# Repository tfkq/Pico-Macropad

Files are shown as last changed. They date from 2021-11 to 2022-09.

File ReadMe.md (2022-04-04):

# Pico-Macropad

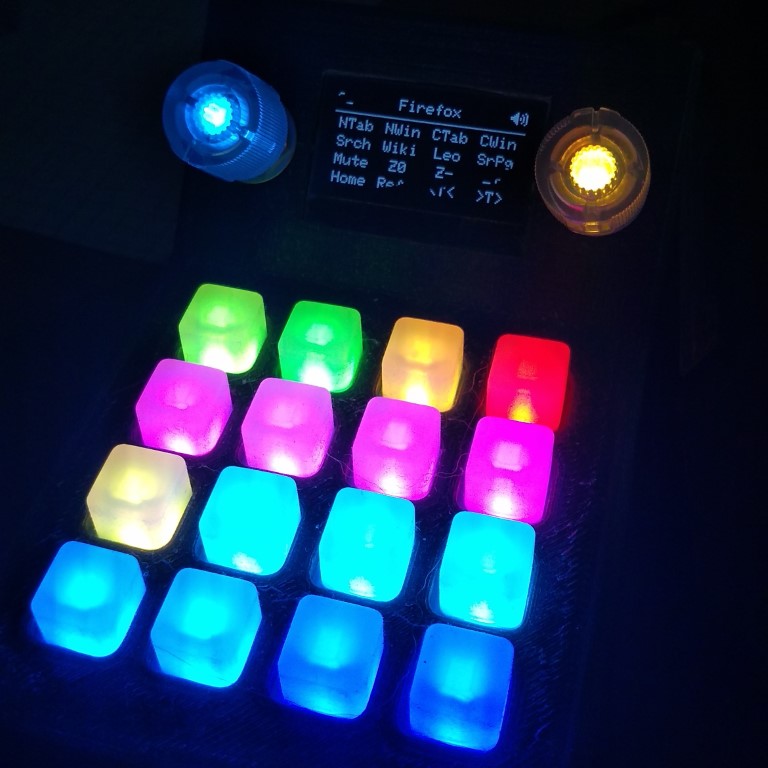
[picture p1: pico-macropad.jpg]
pico-macropad


A custom macropad built out of a Trellis Keypad, a display, rotary encoders and an Raspberry Pi Pico

## Function

This macropad features 16 RGB-lit keys to program to your own pleasure! The display shows the name of each key, so you'll remember what each of these does. Also, thanks to the rotary encoders you are not limited to 16 keys, you can create your own menu for every app you like. To switch between these menus, simply rotate the left encoder. The one on the right is used for media control, so you can adjust the volume and Play/Pause your music.

How to create a configuration: [Config-Creation](#Config-Creation)

## Construction

### Materials and parts

| Part | Cost | Links |
| --- | --- | --- |
| Raspberry Pi Pico | 4.10 €  | [Berrybase](https://www.berrybase.de/neu/raspberry-pi-pico-rp2040-mikrocontroller-board?c=2461) |
| Sparkfun RGB Rotary Encoder (2x) | 9.30 €  | [Berrybase](https://www.berrybase.de/bauelemente/passive-bauelemente/potentiometer/drehimpulsgeber/rotary-encoder/inkrementalgeber-rgb-beleuchtet) |
| Rotary knob, transparent (2x) | 1.80 €  | [Berrybase](https://www.berrybase.de/bauelemente/passive-bauelemente/potentiometer/drehpotis/drehknopf-f-252-r-ger-228-ndelte-6-0mm-achse-transparent) |
| Adafruit NeoTrellis Driver PCB | 12.90 € | [Berrybase](https://www.berrybase.de/neu/adafruit-neotrellis-rgb-treiber-pcb-f-252-r-4x4-keypad?c=2434) |
| Adafruit Silikon Elastomer 4x4 Button Keypad | 5.10 €  | [Berrybase](https://www.berrybase.de/sensoren-module/eingabe/adafruit-silikon-elastomer-4x4-button-keypad-f-252-r-3mm-leds) |
| Monochromes 1.3" 128x64 OLED Display - STEMMA QT / Qwiic | 20.55 € | [Berrybase](https://www.berrybase.de/sensoren-module/displays/oled-displays/monochromes-1.3-128x64-oled-display-stemma-qt/qwiic) |
| Screws, 3mm in diameter, 16mm in length (4x) | ? | had them laying around |

### 3D-prints

I designed my own case and printed it with PLA ([Blue Pearl](https://www.dasfilament.de/filament-spulen/pla-1-75-mm/405/pla-filament-1-75-mm-blue-pearl?c=11)). I've put the Skynet logo on the front, because I felt the need to put something there and I have just watched Terminator 2. You can find the CAD and STL files in `doc/cad-files/`.

### Assembly

1. Wiring:
	There are some images of the wiring in the `doc` folder. However, there are some errors in the schematics that I haven't fixed yet.
2. Putting the parts together:
	I used four screws with a diameter of 3mm and a length of 16mm
	I taped some foam on top of the legs for the trellis board, so it can't wiggle too much

## Programming

### Platform
I chose the Raspberry Pi Pico because of its speed and ability to emulate a keyboard. But for the programming part I sticked with the Arduino platform, because I already know how it works and is compatible with all devices. This was a problem with micropython, as it doesn't have widespread support for every module imaginable. I also decided myself against Cuircuit-Python, once because using a display with it is kinda a struggle, second because I programmed enough Python in the past, and I wanted to practice a little bit of C++.

Secondly, as I had some trouble sending special keycodes (Volume UP and DOWN, Play/Pause, etc) with the Keyboard-library, I decided to send a special shortcut instead, wich would be caught by an AutoHotKey script (It's Windows only, sadly, other platforms would need to search for an alternative).

### Source-Code for RPi Pico

The source-code is divided into different files, here is a short summary of them:

| file | description |
| --- | --- |
| **Pico-Macropad.ino** | main file, brings everything together by telling the other modules what to do |
| config.h | saves the configuration of shrotcuts |
| display.h | controls the OLED-display |
| display_animation.h | saves data for the startup-animation on the display |
| led_controller.h | responsible for setting the brightness of all the leds |
| neotrellis.h | controls and reads the Adafruit Neotrellis board |
| rotary_encoder.h | controls and reads the two rotary encoders |
| shortcut.h | uses the the `Keyboard.h`-library to send the sortcuts to your PC |
| *macropad.ahk* | the AHK-script. Not necessarily the one I'm using, but it is A script |

### AutoHotKey-Script

At first I wanted to create every shortcut inside the C++-program. However, I wanted to build a [Config-Creator](https://github.com/zauberwild/Pico-Macropad-Config-Creator) to create the shortcuts with a GUI. This means, that the Pico will send a generic shortcut (`F24` + something), which will be catched by an AHK-script. Finally, the script will perform all the tasks.

### Config Creation

To create a Configuration, you need to head over to my [Config-Creator](https://github.com/zauberwild/Pico-Macropad-Config-Creator).

## Credits and License

This project is under the MIT license. If you reuse any parts of this and publish it, please be so kind to mention me / this repo.

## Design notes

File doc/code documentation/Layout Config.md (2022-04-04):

# Layout Config

This file describes the format of the config files found in `/data`.

> Example of config file:
> ````
> MAIN	255	0	0
> Micro	$F240#0.	255	255	0
> Prev	$F240#1.	255	191	0
> Next	$F240#2.	255	191	0
> Lock	$F240#3.	255	127	0
> StandBy	$F240#4.	255	64	0
> ShutDn	$F240#5.	255	0	0
> -
> -
> -
> ~PROGRA
> -
> -
> ````

**Layout Name and Color**

The first line contains the Layout name (max. 6 chars.) and color as RGB (0-255)

**Buttons**

The Buttons are given in the following lines, each line for one button.'
These lines also contain the name for the button (max. 6 chars.), then the macros (max. 63 chars.), then the color as RGB (0-255)

**Formatting**

The different fields are always seperated by `TABs`, so that Spaces can still be used if wanted to.

**Special Signs**

| Sign | |
| --- | --- |
| **`-`** | empty field. this button will not perform any action and will be turned off |
| **`~`** | special functions. there will no macros performed on these buttons. Instead a function will be called.<br />Names for these fields can be given after the `~` (max. 6 char.; without  `~`) |

*Sign `~`:*

- `~PROG`: change the selected layout

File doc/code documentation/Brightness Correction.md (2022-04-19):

# Brightness Correction

When turning the rotary encoder for brightness, the scale, and thus the brightness, would be changed linearly. However, the resulting change of brightness doesn't seem linear to the human eye, and in order to fix that, I used a ~~logistic~~ *apparently exponential* function, that would convert the mathematically linear scale to perceptually linear scale.

> inspired from this answer on stack-exchange: https://electronics.stackexchange.com/a/11100

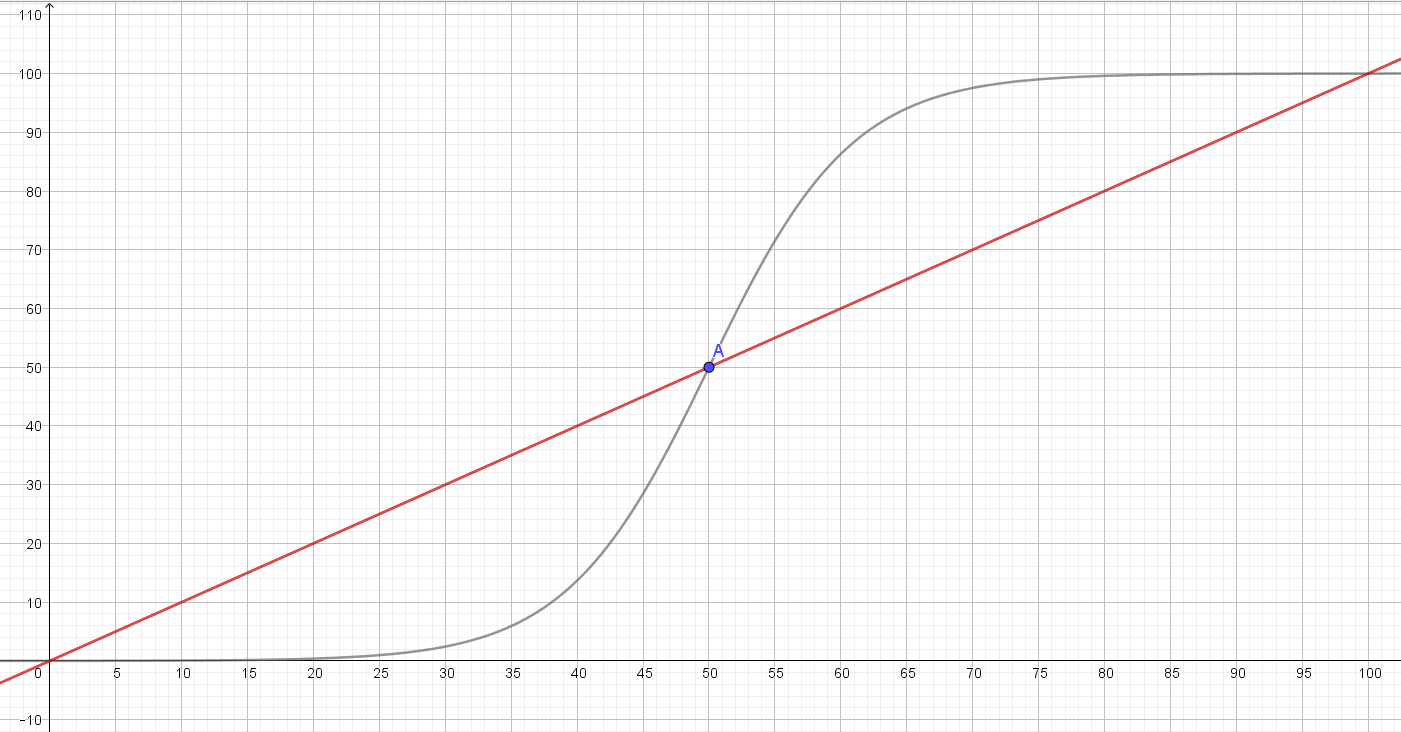
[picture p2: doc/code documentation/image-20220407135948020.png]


In the above image, the red line shows the linear scale of the direct input. The dark line is the logistic scale which should be applied to the LED's.

The function for logistic growth looks like this:
$$
f(x) = \frac{
	G \cdot f_0
}{
	f_0 + (G-f_0) \cdot e^{
		-k\cdot G \cdot x
	}
}
$$
Where $G$ is the upper boundary, $f_0$ the value of $f(0)$ and $k$ a factor (as it seems in $]0,1[$ ).

We know that $G=100$ and $f_0 = 0.01 \approx 0$ (the lowest value would be zero, but the function doesn't allow a start at zero, so we approximate it with 0.001). Also we know  that $f(x)$ includes $P(50|50)$. This way we can calculate $k$:
$$
\begin{align}
50 &= \frac{
	100 \cdot 0.01
}{
	0.01 + (100 - 0.01) \cdot e^{
		-k \cdot 100 \cdot 50
	}
}
\\
k &= 0.00184
\end{align}
$$

This gives us the equation for a corrected brightness:
$$
\begin{align}
\text{brightness} &= \frac{
	100 \cdot 0.01
}{
	0.01 + (100-0.01) \cdot
	e^{
		-0.00184 \cdot 100 \cdot \text{raw\_brightness}
	}
}
\\
\text{brightness} &= \frac{
	1
}{
	0.01 + (99.99) \cdot 
	e^{
		-0.184 \cdot \text{raw\_brightness}
	}
}
\\
\\
\text{brightness} &\approx \frac{
	1
}{
	100 \cdot 
	e^{
		-0.184 \cdot \text{raw\_brightness}
	}
}
\end{align}
$$
Which leads to the final code:

````c++
brightness = 1 / (100 * pow(2.718, -0.184 * raw_brightness));
if(brightness < 0 )
    brightness = 0;
else if(brightness > 100)
    brightness = 100;
````

---

EDIT:

the optimised function (in green) isn't logistic at all and doesn't strictly meet my requirements:

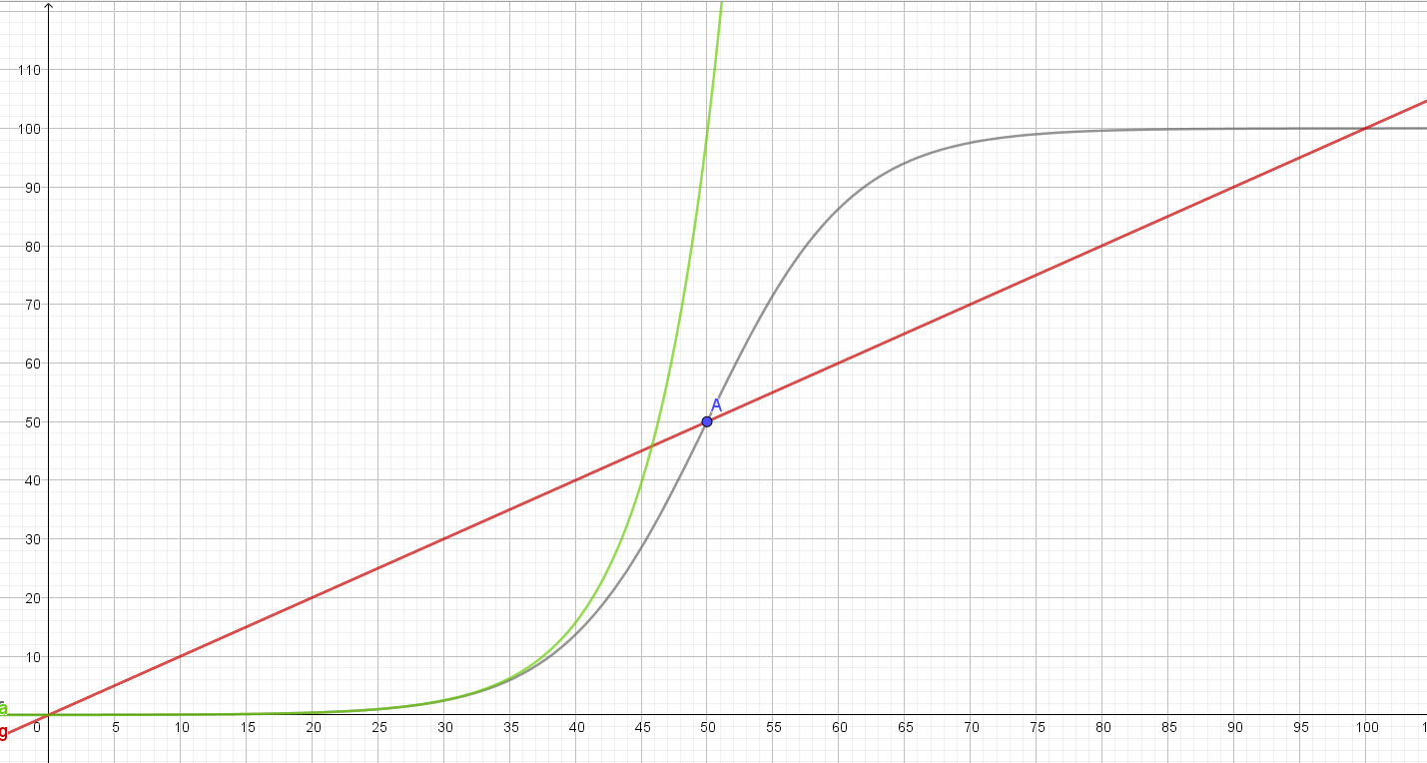
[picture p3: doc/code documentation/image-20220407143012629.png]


However, it still works well enough, except that i need to cap `raw_brightness` a little bit earlier than 100, but at 50. *it even feels somewhat better than not optimised logistic.*

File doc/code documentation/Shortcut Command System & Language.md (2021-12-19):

# Shortcut Command System & Language

I created my own Command Language which would be easy to parse and doesn't require line breaks. This system supports all modifier on Windows (and maybe UNIX, but I haven't tested) and special keys to be pressed and released in whatever order.

## Sending letters / text

To send plain text you just use ... plain text! For example if you want a macro typing "Hello World!" for you, you would just type it like that.

However, there are some problems when your computer is set to a keyboard-layout other than the standard English (QWERTY) one. Especially special letters (@,#,+,*,...) are problematic, and I couldn't find a way to fix this yet. 

## Commands

Generally speaking, all commands start with `$` and only contain two letters, with some exceptions. There are also two type of commands: First the modifier keys, which are toggled when using its command. The first use presses the key down, the second one releases its, and so on. Second, other special keys, like Enter/Return, Insert, Delete, etc. These are just pressed once and than you're done. Following is a list with all commands.

**One important thing: the command system is Case-Sensitive.**

### Toggled commands

1. *these are always the one on the left side of the keyboard*
2. *the keyword in the bracket is the input to the [Keyboard library](https://www.arduino.cc/reference/en/language/functions/usb/keyboard/) (`Keyboard.print(<Keyword>);`)*
3. *as mentioned, these keys are toggled on and off, so don't forget to toggle them off at the end*

| Command | Explanation |
| --- | --- |
| $W | Windows / Meta key (`KEY_LEFT_GUI`) |
| $C | Control Key (`KEY_LEFT_CTRL`) |
| $S | Shift Key (`KEY_LEFT_SHIFT`) |
| $A | Alt Key (`KEY_LEFT_ALT`) |

### Special keys

- *these are just pressed once and will be quickly released*

| Command | Explanation |
| --- | --- |
| $E | Enter / Return |
| $T | Tab |
| $* | Escape |
| $1 | Home / Pos1 |
| $0 | End |
| $I | Insert |
| $D | Delete |
| $$ | $ (in case you need a dollar sign) | |
| $Fxx | All the F-keys your computer supports. "xx" can be replaced with a number from 1 to 24 |
| $dxxxx$ | This one starts a delay. The time is given in milliseconds and is limited to four digits. Please note that this stops the whole program and it waits until the time is past. You won't be able to do other things with it in the meantime. |

### Examples

- `$We$W` opens the explorer on Windows
- `$Cko$C` opens a folder in VS Code
- `$Wr$W$d250$cmd$E` starts the command palette (the delay gives Windows enough time to start Run)
- `$We$W$d500$vv$E$d250$g$E$d250$a$E$d259$r$E`: This beast starts the explorer, navigates to my folder of this project and opens the ReadMe

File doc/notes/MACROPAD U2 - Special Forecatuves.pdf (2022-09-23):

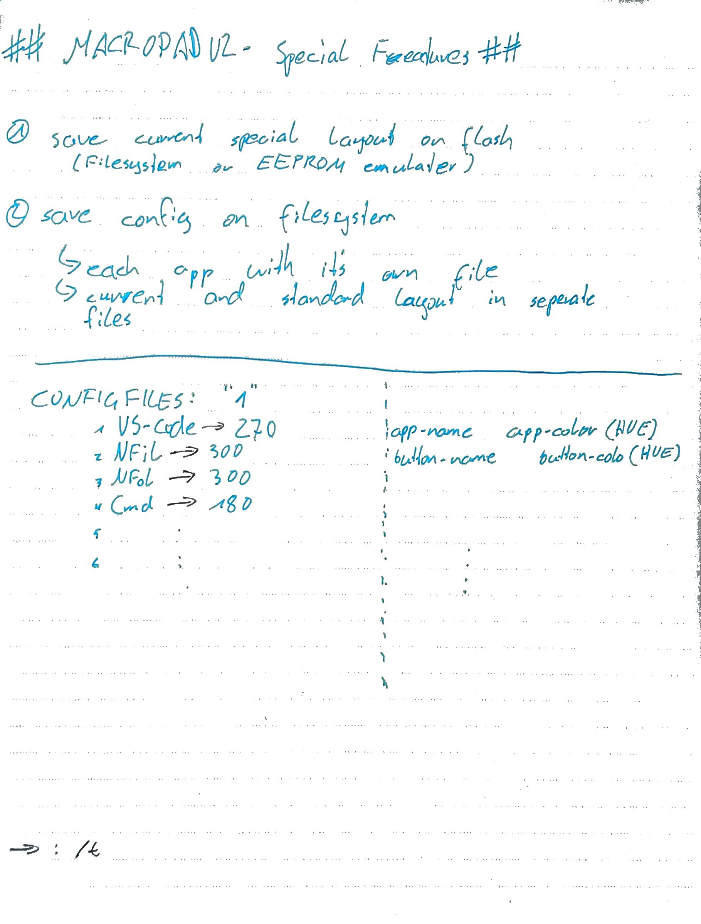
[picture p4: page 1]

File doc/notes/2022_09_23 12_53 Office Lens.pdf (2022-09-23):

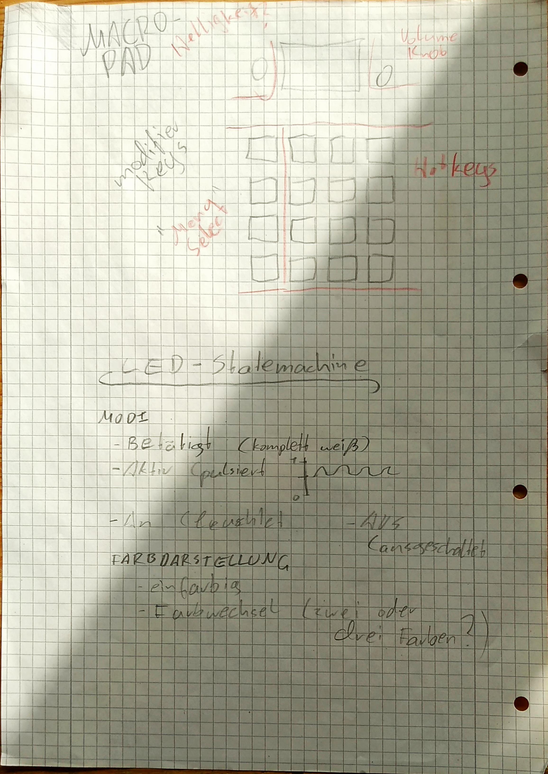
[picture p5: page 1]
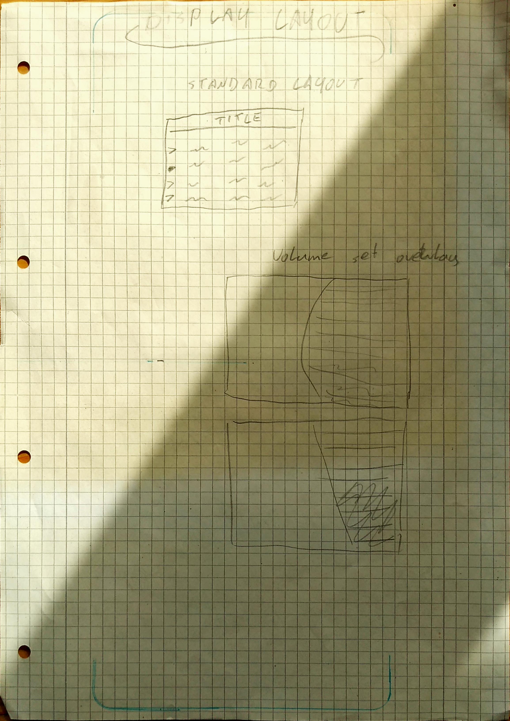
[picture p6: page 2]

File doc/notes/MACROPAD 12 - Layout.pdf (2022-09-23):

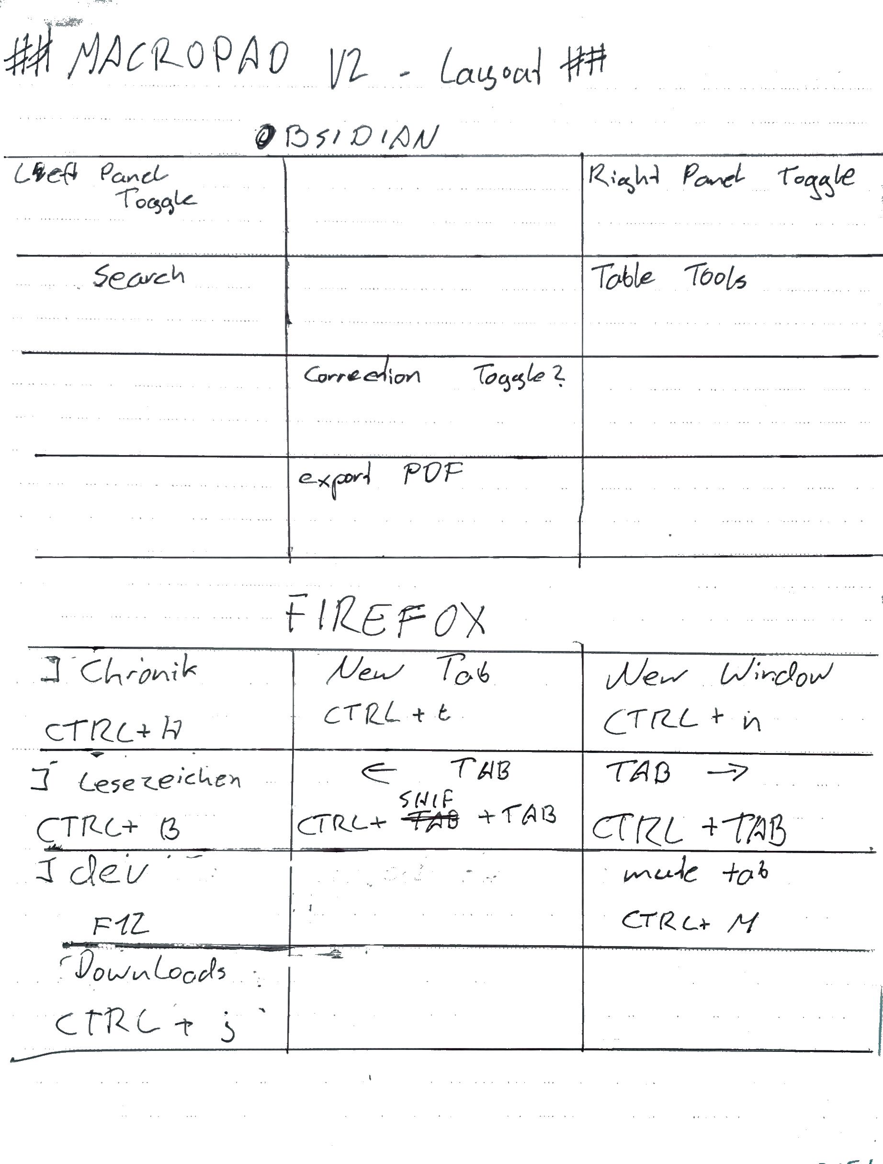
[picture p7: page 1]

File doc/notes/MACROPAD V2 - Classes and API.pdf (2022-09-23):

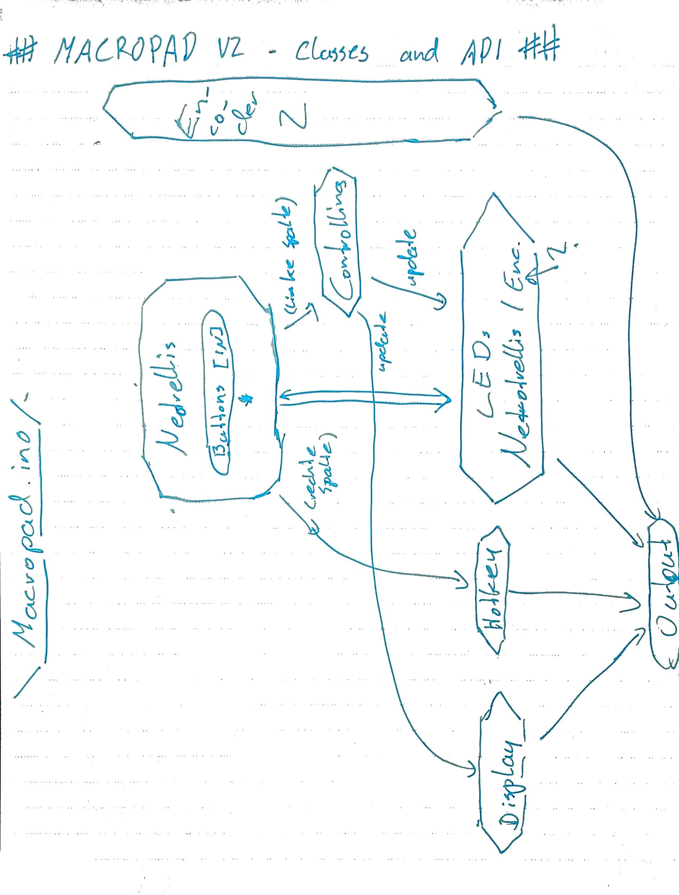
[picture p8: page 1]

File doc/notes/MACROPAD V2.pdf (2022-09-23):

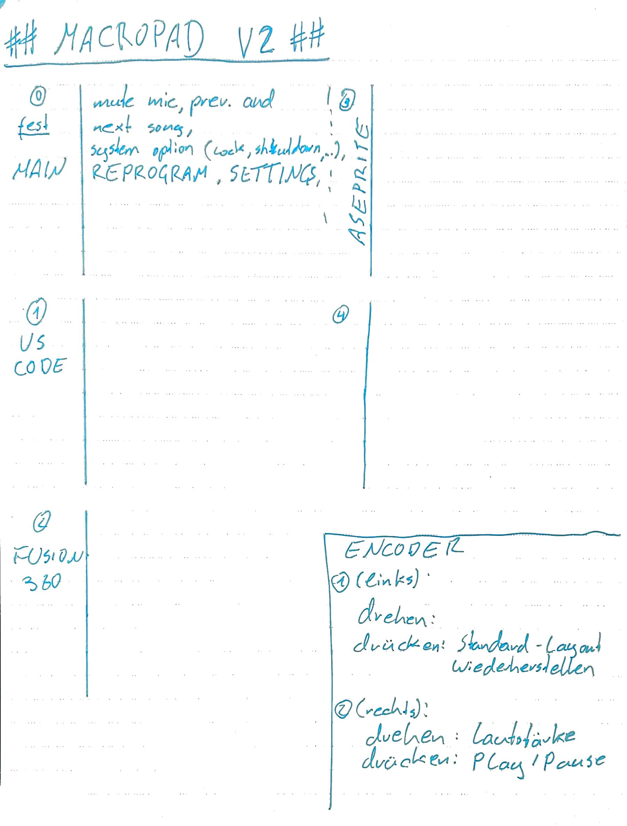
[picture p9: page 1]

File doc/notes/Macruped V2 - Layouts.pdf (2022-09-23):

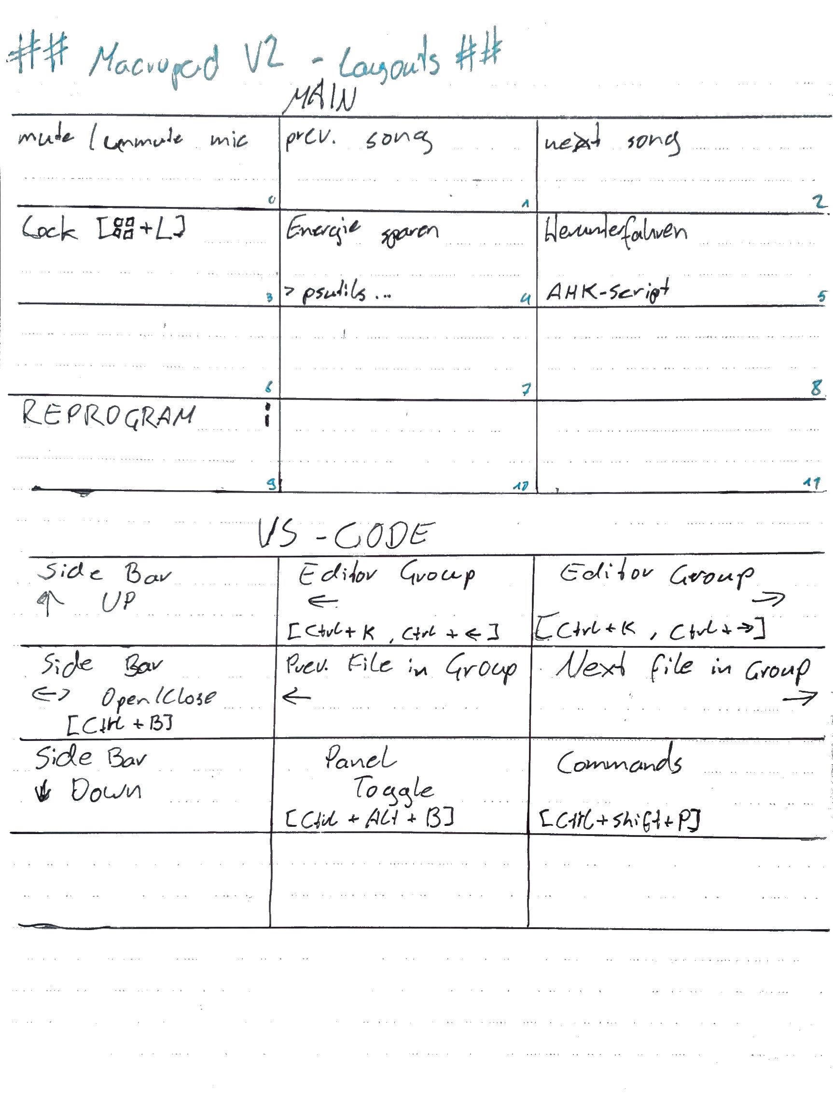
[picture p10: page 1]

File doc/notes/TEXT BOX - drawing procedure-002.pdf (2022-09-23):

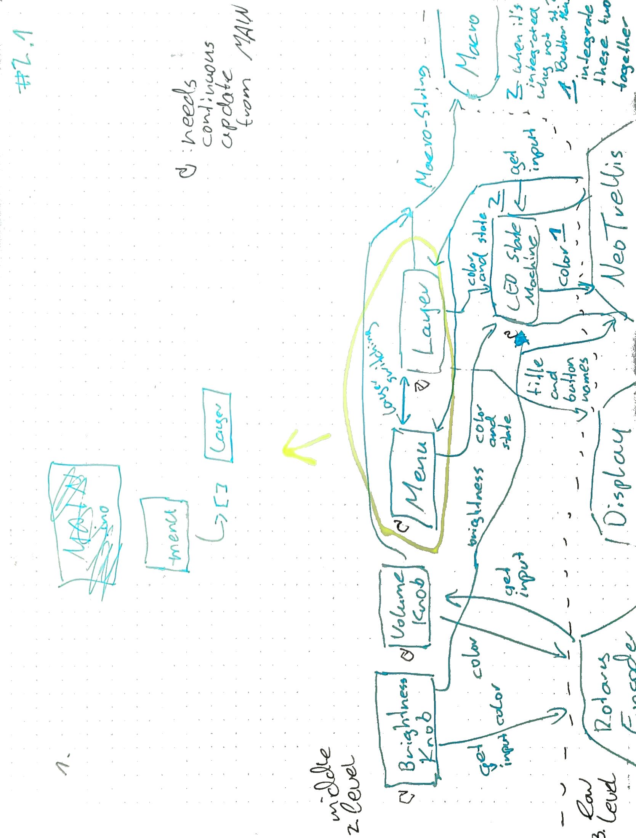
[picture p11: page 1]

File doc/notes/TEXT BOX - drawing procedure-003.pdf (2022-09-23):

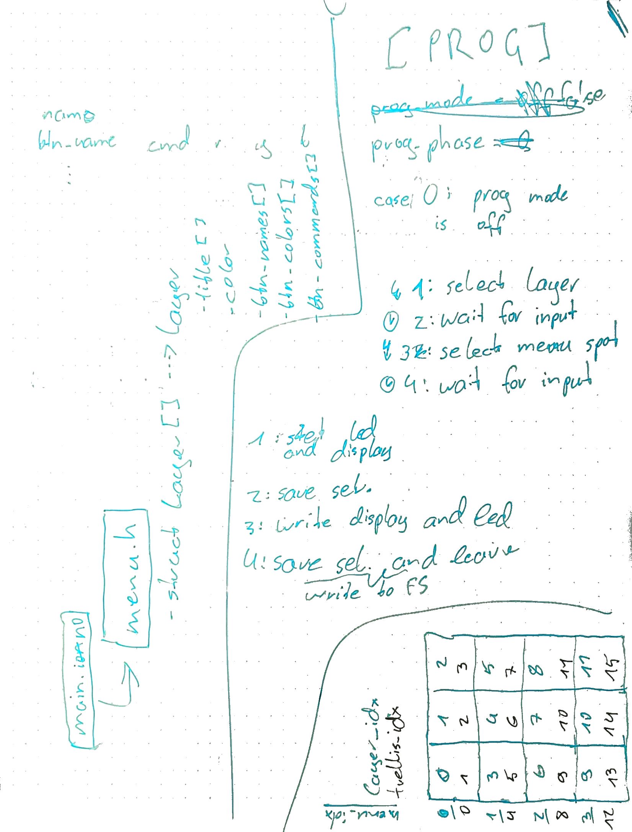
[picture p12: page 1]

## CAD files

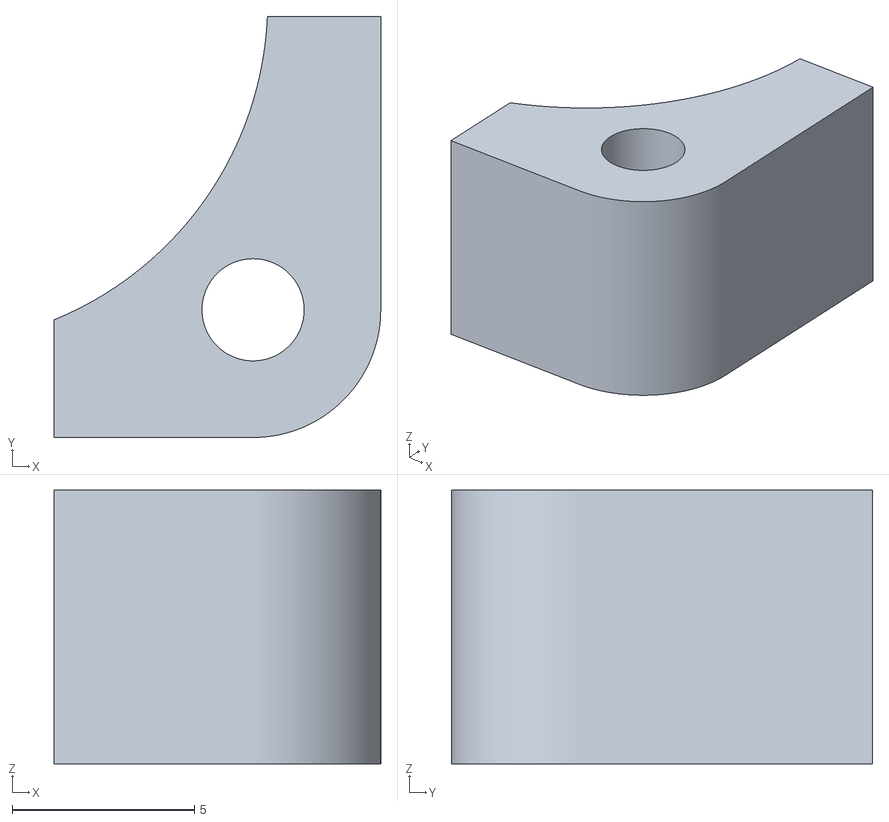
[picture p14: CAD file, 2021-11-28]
doc/cad-files/Halterung vorne 1.stl
8.95 x 11.5 x 7.50

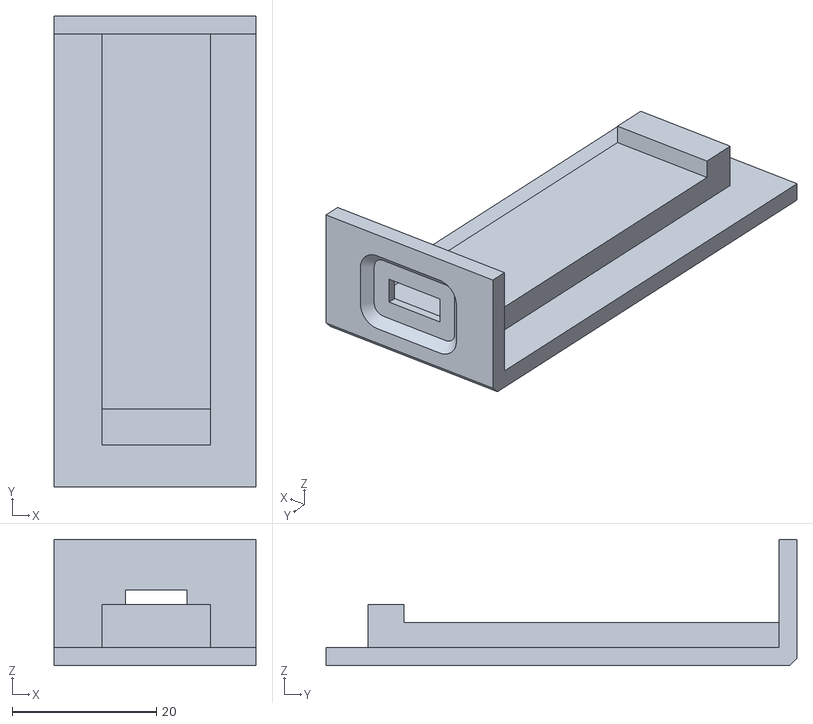
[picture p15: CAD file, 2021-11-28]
doc/cad-files/test files/Pico.stl
28.0 x 65.3 x 17.5

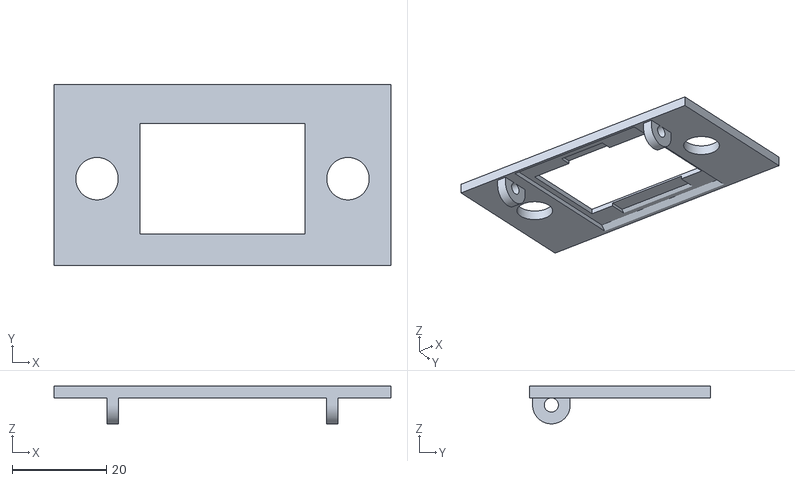
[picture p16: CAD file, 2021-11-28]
doc/cad-files/test files/DisplayUndRot.stl
71.5 x 38.4 x 8.00

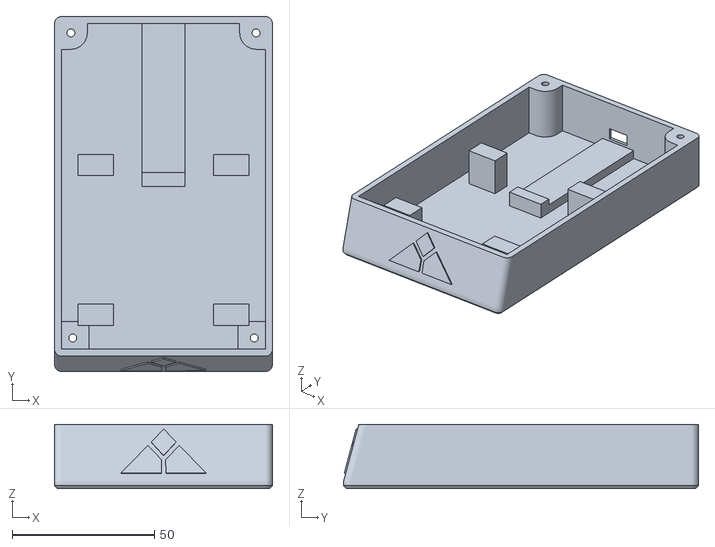
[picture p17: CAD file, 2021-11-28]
doc/cad-files/Unterseite_25mm_Skynet.stl
76.5 x 124.6 x 22.5

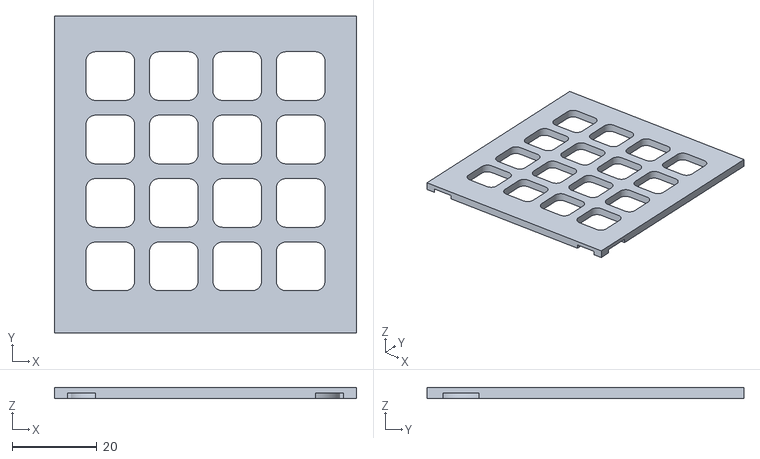
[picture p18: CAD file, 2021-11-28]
doc/cad-files/test files/TrellisKeypad.stl
71.5 x 74.9 x 2.50

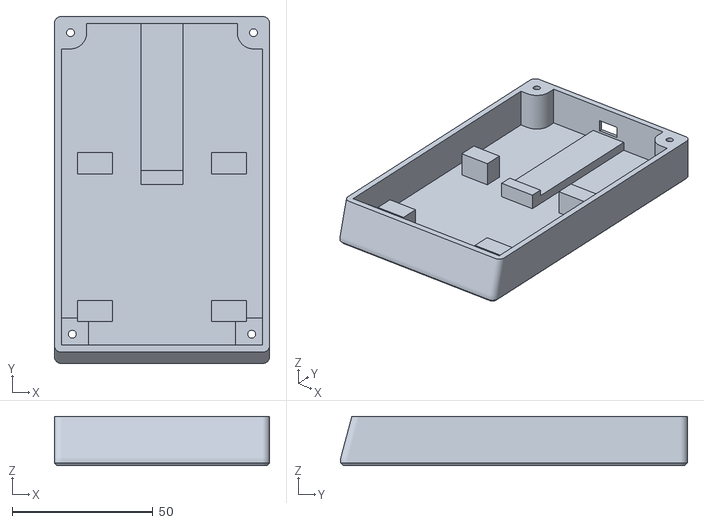
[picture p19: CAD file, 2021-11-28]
doc/cad-files/Unterseite_20mm.stl
76.5 x 123.2 x 17.5

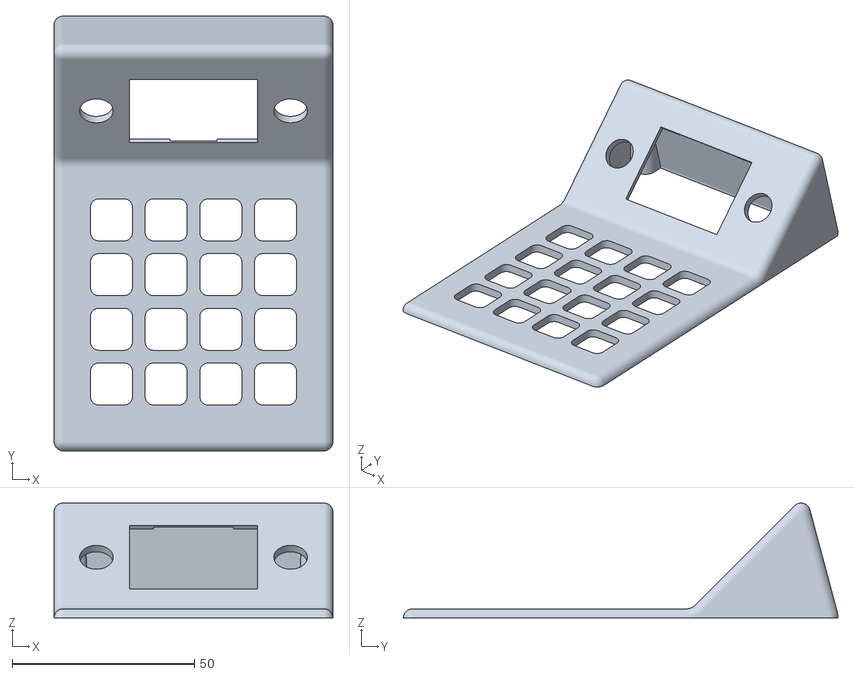
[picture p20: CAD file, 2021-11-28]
doc/cad-files/Oberseite.stl
76.5 x 119.2 x 31.5

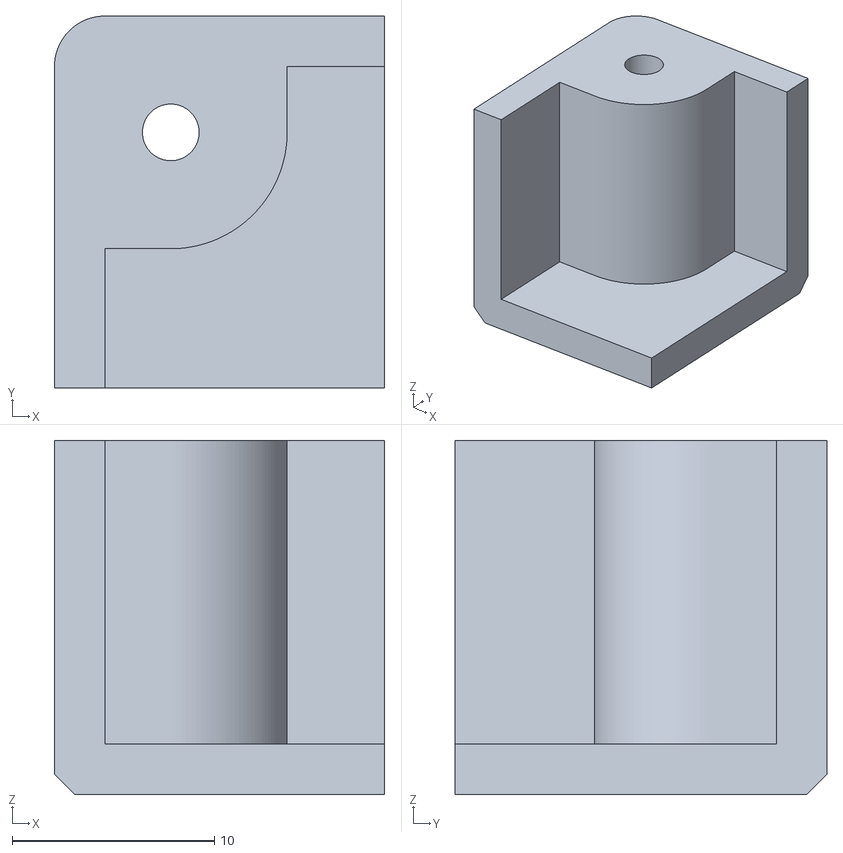
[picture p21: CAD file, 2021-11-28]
doc/cad-files/test files/Screws.stl
16.3 x 18.4 x 17.5

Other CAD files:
doc/cad-files/Halterung vorne 2.stl

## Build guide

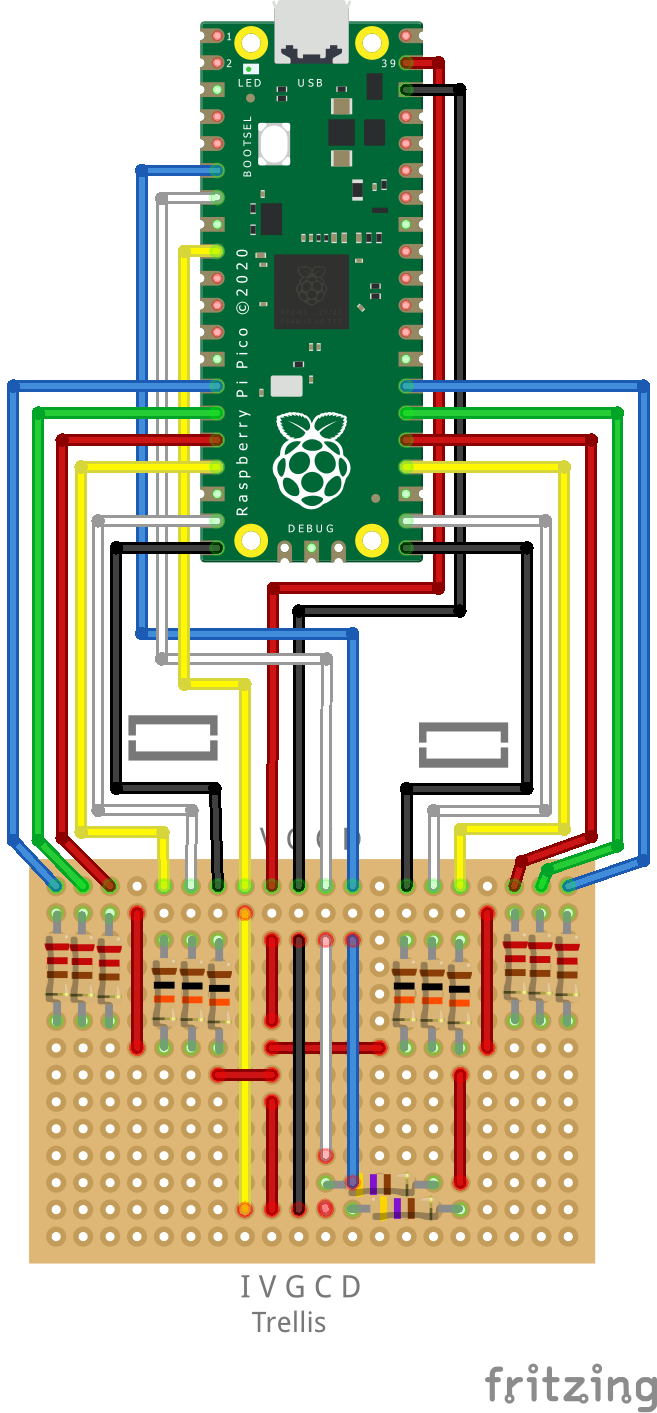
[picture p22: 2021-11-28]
doc/wiring-schematics/wiring pcb_Steckplatine.png

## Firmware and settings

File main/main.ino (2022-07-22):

//* SETTINGS
#define MAX_NAME_LENGTH 6
#define MAX_MACRO_LENGTH 63
#define MAX_NUMBER_LAYOUTS 12
#define DISPLAY_TIMEOUT 5000		 // time it takes for the display to turn off [ms]
#define DISPLAY_UPDATE_TIME 500		 // time between the display updates [ms]
#define TRELLIS_LED_UPDATE_TIME 50	 // time between the led updates [ms]
#define DEBOUNCE_TIME 5				 // debounce time for the rotary encoder [ms]
#define STEPS_PER_VOLUME 1			 // steps the volume knob needs to be turned to send a volume command
#define BRIGHTNESS_STEPS_PER_STEPS 2 // how much does the brightness change per encoder step
double raw_brightness = 40;			 // brightness percentage (0%-100%); used to calculate a corrected version
double brightness;					 // brightness percentage (0%-100%); use this one, because it is corrected

unsigned long last_input = 0; // saves the last time any of the inputs had been changed [ms]

//* INCLUDES
// Arduino libraries
#include <Bounce2.h>
#include <Keyboard.h>
#include <Adafruit_NeoTrellis.h>
#include <Adafruit_GFX.h>
#include <Adafruit_SSD1306.h>
// Pico specific library
#include <LittleFS.h>
// local files
#include "macro.h"
#include "utils.h"
#include "display.h"
#include "rotary_encoder.h"
#include "brightness_knob.h"
#include "volume_knob.h"
#include "neotrellis.h"
#include "button_state_machine.h"
// #include "layer.h"
#include "menu.h"

void setup()
{
	//Serial.begin(9600);
	// while (!Serial)
	// {
	// }

	Menu::begin();

	VolumeKnob::begin();
	BrightnessKnob::begin();
	BrightnessKnob::correct_brightness();
	delay(750);
	NeoTrellis::begin();
	delay(750);
	Display::begin();

	last_input = millis();
}

void loop()
{
	Menu::update();

	Display::update();

	NeoTrellis::update();

	VolumeKnob::update();
	BrightnessKnob::update();
}

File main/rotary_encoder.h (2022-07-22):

/**
 * @file rotary_encoder.h
 * @author zauberwild
 * @brief low-level communication with a rotary encoder
 * @version 2.1
 * @date 2022-04-04
 *
 * @copyright MIT license, Arvid, Randow 2022
 *
 */

#ifndef rotary_encoder_h
#define rotary_encoder_h

#define ROTARY_ENCODER_SW_RISING 3
#define ROTARY_ENCODER_SW_FALLING 2
#define ROTARY_ENCODER_CCW 13
#define ROTARY_ENCODER_CW 12

class RotaryEncoder
{
	// button / encoder
	int a, b, sw;
	Bounce bounce_a = Bounce(); // Bounce for all inputs (makes the debouncing a lot easier)
	Bounce bounce_b = Bounce();
	Bounce bounce_sw = Bounce();
	u_int8_t rot_event;
	u_int8_t sw_event;
	// led
	RGB pins;
	RGB color;
	bool changed = true;
	bool pulse;

public:
	RotaryEncoder();
	RotaryEncoder(int p_a, int p_b, int p_sw, RGB p_pins);
	void begin();
	void update();

	void set_color(RGB p_color);
	void set_color(int hue);
	int get_rot_event();
	int get_sw_event();
};

/**
 * @brief Construct a new Rotary Encoder:: Rotary Encoder object
 * 
 */
RotaryEncoder::RotaryEncoder() {}

/**
 * @brief Construct a new Rotary Encoder:: Rotary Encoder object
 * 
 * @param p_a pin for encoder switch A (or CLK)
 * @param p_b pin for encoder switch B (or Data or Signal)
 * @param p_sw pin for built-in button
 * @param p_pins pins of the rgb-led as RGB(r, g, b)
 */
RotaryEncoder::RotaryEncoder(int p_a, int p_b, int p_sw, RGB p_pins)
{
	a = p_a;
	b = p_b;
	sw = p_sw;
	pins = p_pins;
}

/**
 * @brief initializes the encoder; call once on startup
 * 
 */
void RotaryEncoder::begin()
{
	// set the inputs
	bounce_a.attach(a, INPUT_PULLUP);
	bounce_a.interval(DEBOUNCE_TIME);
	bounce_b.attach(b, INPUT_PULLUP);
	bounce_b.interval(DEBOUNCE_TIME);
	bounce_sw.attach(sw, INPUT);
	bounce_sw.interval(DEBOUNCE_TIME);

	// set the leds
	pinMode(pins.r, OUTPUT);
	pinMode(pins.g, OUTPUT);
	pinMode(pins.b, OUTPUT);
}

/**
 * @brief update the encoder; must be called repeatedly without delay
 * 
 */
void RotaryEncoder::update()
{
	//* rotating fun
	bounce_a.update();
	bounce_b.update();
	rot_event = 0;
	if (bounce_a.changed() && bounce_a.read() == LOW)
	{
		last_input = millis();
		if (bounce_b.read() == HIGH)
		{
			rot_event = ROTARY_ENCODER_CW;
		}
		else
		{
			rot_event = ROTARY_ENCODER_CCW;
		}
	}

	//NOTE Schriftart herunterladen

	//* clicking fun
	bounce_sw.update();
	sw_event = 0;
	if (bounce_sw.changed())
	{
		last_input = millis();
		Display::announce_change();
		pulse = bounce_sw.read();
		changed = true;
		if (bounce_sw.read() == HIGH)
		{
			sw_event = ROTARY_ENCODER_SW_RISING;
		}
		else
		{
			sw_event = ROTARY_ENCODER_SW_FALLING;
		}
	}

	//* blinky-blinky fun
	if (changed)
	{
		changed = false;
		RGB actual_color = color;
		if (pulse)
		{
			actual_color = RGB(255, 255, 255);
		}

		float enc_brightness = brightness * 2;
		if (enc_brightness < 0)
			enc_brightness = 0;
		else if (enc_brightness > 100)
			enc_brightness = 100;
		
		enc_brightness /= 100;

		analogWrite(pins.r, 255 - (actual_color.r * enc_brightness));
		analogWrite(pins.g, 255 - (actual_color.g * enc_brightness));
		analogWrite(pins.b, 255 - (actual_color.b * enc_brightness));
	}
}

/**
 * @brief set the color of the encoder
 * 
 * @param p_color color as RGB
 */
void RotaryEncoder::set_color(RGB p_color)
{
	color = p_color;
	changed = true;
}

/**
 * @brief set the color of the encoder
 * 
 * @param hue hue of the color (saturation and value are assumed to be 100%)
 */
void RotaryEncoder::set_color(int hue)
{
	color = hue_to_rgb(hue);
	changed = true;
}

/**
 * @brief get any event from the rotating bit
 * 
 * @return int 0: no event; ROTARY_ENCODER_CW when turning clockwise; ROTARY_ENCODER_CCW when turning counterclockwise
 */
int RotaryEncoder::get_rot_event()
{
	return rot_event;
}

/**
 * @brief get any event from the clicky bit
 * 
 * @return int 0: no event; ROTARY_ENCODER_SW_RISING or ROTARY_ENCODER_SW_FALLING when value changed
 */
int RotaryEncoder::get_sw_event()
{
	return sw_event;
}

#endif

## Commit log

2021-11-26 2. initial commit
    [DisplayUndRot.stl, Halterung vorne 1.stl, Halterung vorne 2.stl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]
2021-11-28 Create 2021_11_26 23_00 Office Lens.pdf
    documentation
2021-12-18 Update rotary_encoder.h
    corrected hotkeys for volume and media
    [rotary_encoder.h]
2021-12-19 reorganization of files
    [wiring pcb.fzz]
2021-12-26 Update rotary_encoder.h
    fixed that the encoder would do immediate when in sleeping mode. now it only wakes the macropad up
    [rotary_encoder.h]
2021-12-26 Update led_controller.h
    refined displayStatus and added rotaryStatus
2022-04-04 🔧 added Platform.io files for better development
    still compiling with Arduino IDE though
2022-04-04 📝
    and typos
2022-04-04 renamed pico-macropad.ahk
